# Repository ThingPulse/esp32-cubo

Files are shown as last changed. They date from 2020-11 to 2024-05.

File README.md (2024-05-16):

# ESP32-Cubo

The ESP32-Cubo is a device based on the Espressif ESP32 and comes with the following hardware:
- ESP32 Wrover-B Microcontroller module with 4MB Flash and 8MB SPIRAM memory
- Good Display 1.54" epaper display with 200x200 Black and White Pixels
- Battery charger and connector for LiPo battery
- USB connector for programming and charging
- CP2104 USB-to-Serial Chip
- 2x User controllable LEDs, red and green
- Inertial Measurement Unit ADXL345
- MAX17055 Fuel Gauge Chip for measuring battery voltage and estimating remaining capacity
- DS3231 Real Time Clock Chip for keeping time, powered by coin cell battery
- Reset Button

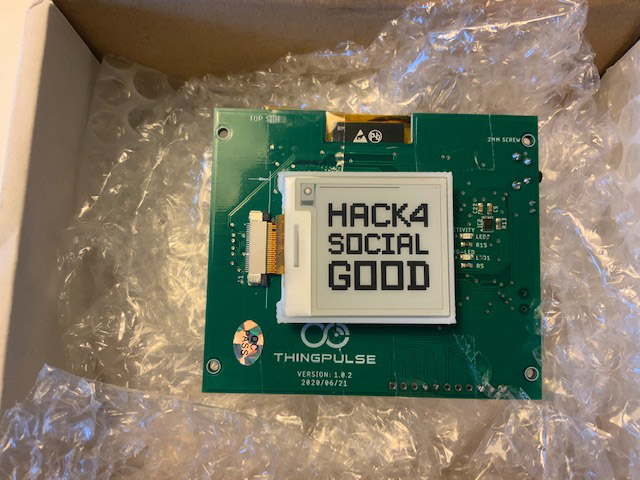
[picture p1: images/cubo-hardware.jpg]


## Template for building a cardboard mockup
[Download cardboard template](/images/Cubo_Vorlage.pdf)

## Prerequisites
- esp32-cubo hardware
- usb cable to connect your computer to the device. 
- git installed on your command line
- experience in programming the ESP32 by using the Arduino platform

## Install the CP2102 driver

This driver is required to programm the esp32-cubo. It enables your computer to talk to the USB-to-Serial chip on the PCB.
To install the driver please follow the instructions under https://www.silabs.com/developers/usb-to-uart-bridge-vcp-drivers

## Setup Development environment

This sample code should in theory work with the Arduino IDE. Instead we suggest to use the Platformio IDE since it makes it
much easier to handle the correct libraries.

Platform IO IDE is a plugin for Microsoft's Visual Studio Code Editor. To install the Platformio IDE please follow
these instructions: https://platformio.org/install/ide?install=vscode

## Get the Code

To get the sample code run 

```
git clone https://github.com/thingpulse/esp32-cubo
```
from your command line or download the zip file from https://github.com/ThingPulse/esp32-cubo/archive/master.zip and unpack it. 

## Components Explained

### The ePaper Display

The 1.54" ePaper display has 200x200 black and white pixels. The display can maintain the state of the pixels even without
supporting power. This makes is a great tool for devices running from batteries since it only consumes energy during updates.

In this sample we use the ThingPulse Minigrafx library to control the display. You can find more information for programming
the display here: https://github.com/ThingPulse/minigrafx/blob/master/API.md

### The ADXL345 IMU

The ADXL345 chip can measure movement/accelereation in three axes. It can wakeup the main processor from deep sleep
when movement is detected. It can also be setup to detect taps  or double taps in one of the three axes. This repository
contains a slightly modified copy of a ADXL345 driver by Korneliusz Jarzebski

## Uploading Filesystem

In order to have the files under data/ available they need to be uploaded to the device first. Platformio creates a .bin file
which is then flashed to the device. Everytime you change the content under data/ this needs to be done. To this execute the following
task: env:esp-wrover-kit > Platform > Upload Filesystem Image

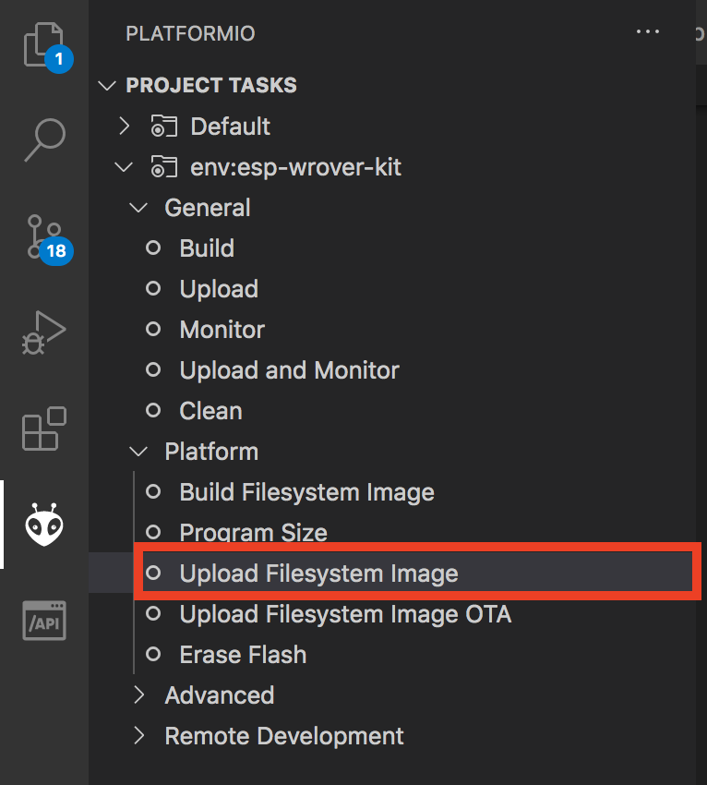
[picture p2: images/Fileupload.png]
File Upload


## Upload Code

To compile the code you can click on the checkmark icon in VS Code's footer. The arrow to the right will do the same and upload
the binary to the device. To plug icon turns on the serial console to monitor what is happening on the device.

Visual Studio Code Footer

## License

Copyright (c) 2020 - 2024, ThingPulse Ltd., Switzerland. All rights reserved.
Hardware is licensed under Creative Commons [CC BY-SA 4.0](https://creativecommons.org/licenses/by-sa/4.0/).
Software is licensed under MIT License, see [LICENSE](LICENSE).

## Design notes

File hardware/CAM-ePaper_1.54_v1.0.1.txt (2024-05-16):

{
    "author": {
        "email": "support.eagle@autodesk.com",
        "name": "Autodesk EAGLE"
    },
    "description": {
        "EN": "EAGLE default 2 layer CAM job."
    },
    "output_type": "zip",
    "outputs": [
        {
            "filename_prefix": "CAMOutputs/GerberFiles",
            "format_specifier": {
                "decimal": 4,
                "integer": 3
            },
            "generate_job_file": true,
            "output_type": "gerber",
            "outputs": [
                {
                    "advanced_options": {
                        "mirror": false,
                        "offset_x": 0,
                        "offset_y": 0,
                        "rotate": false,
                        "upside_down": false
                    },
                    "board_outline": false,
                    "config": {
                        "file_function": "Copper",
                        "layer": 1,
                        "layer_details": "mixed",
                        "layer_type": "top"
                    },
                    "filename_format": "%PREFIX/copper_top.gbr",
                    "layers": [
                        1,
                        17,
                        18
                    ],
                    "name": "Top Copper",
                    "polarity": "positive",
                    "type": "gerber_layer"
                },
                {
                    "advanced_options": {
                        "mirror": false,
                        "offset_x": 0,
                        "offset_y": 0,
                        "rotate": false,
                        "upside_down": false
                    },
                    "board_outline": false,
                    "config": {
                        "file_function": "Copper",
                        "layer": 2,
                        "layer_details": "mixed",
                        "layer_type": "bottom"
                    },
                    "filename_format": "%PREFIX/copper_bottom.gbr",
                    "layers": [
                        16,
                        17,
                        18
                    ],
                    "name": "Bottom Copper",
                    "polarity": "positive",
                    "type": "gerber_layer"
                },
                {
                    "advanced_options": {
                        "mirror": false,
                        "offset_x": 0,
                        "offset_y": 0,
                        "rotate": false,
                        "upside_down": false
                    },
                    "board_outline": true,
                    "config": {
                        "file_function": "Profile",
                        "plating": "non-plated"
                    },
                    "filename_format": "%PREFIX/profile.gbr",
                    "layers": [
                    ],
                    "milling": true,
                    "polarity": "positive",
                    "type": "gerber_layer"
                },
                {
                    "advanced_options": {
                        "mirror": false,
                        "offset_x": 0,
                        "offset_y": 0,
                        "rotate": false,
                        "upside_down": false
                    },
                    "board_outline": false,
                    "config": {
                        "file_function": "Soldermask",
                        "index": 1,
                        "layer_type": "top"
                    },
                    "filename_format": "%PREFIX/soldermask_top.gbr",
                    "layers": [
                        29
                    ],
                    "name": "Soldermask Top",
                    "polarity": "positive",
                    "type": "gerber_layer"
                },
                {
                    "advanced_options": {
                        "mirror": false,
                        "offset_x": 0,
                        "offset_y": 0,
                        "rotate": false,
                        "upside_down": false
                    },
                    "board_outline": false,
                    "config": {
                        "file_function": "Soldermask",
                        "index": 1,
                        "layer_type": "bottom"
                    },
                    "filename_format": "%PREFIX/soldermask_bottom.gbr",
                    "layers": [
                        30
                    ],
                    "name": "Soldermask Bottom",
                    "polarity": "positive",
                    "type": "gerber_layer"
                },
                {
                    "advanced_options": {
                        "mirror": false,
                        "offset_x": 0,
                        "offset_y": 0,
                        "rotate": false,
                        "upside_down": false
                    },
                    "board_outline": false,
                    "config": {
                        "file_function": "Paste",
                        "layer_type": "top"
                    },
                    "filename_format": "%PREFIX/solderpaste_top.gbr",
                    "layers": [
                        31
                    ],
                    "milling": false,
                    "name": "Solderpaste Top",
                    "polarity": "positive",
                    "type": "gerber_layer"
                },
                {
                    "advanced_options": {
                        "mirror": false,
                        "offset_x": 0,
                        "offset_y": 0,
                        "rotate": false,
                        "upside_down": false
                    },
                    "board_outline": false,
                    "config": {
                        "file_function": "Paste",
                        "layer_type": "bottom"
                    },
                    "filename_format": "%PREFIX/solderpaste_bottom.gbr",
                    "layers": [
                        32
                    ],
                    "milling": false,
                    "name": "Solderpaste Bottom",
                    "polarity": "positive",
                    "type": "gerber_layer"
                },
                {
                    "advanced_options": {
                        "mirror": false,
                        "offset_x": 0,
                        "offset_y": 0,
                        "rotate": false,
                        "upside_down": false
                    },
                    "board_outline": false,
                    "config": {
                        "file_function": "Legend",
                        "index": 1,
                        "layer_type": "top"
                    },
                    "filename_format": "%PREFIX/silkscreen_top.gbr",
                    "layers": [
                        21,
                        25,
                        51
                    ],
                    "milling": false,
                    "name": "Silkscreen Top",
                    "polarity": "positive",
                    "type": "gerber_layer"
                },
                {
                    "advanced_options": {
                        "mirror": false,
                        "offset_x": 0,
                        "offset_y": 0,
                        "rotate": false,
                        "upside_down": false
                    },
                    "board_outline": false,
                    "config": {
                        "file_function": "Legend",
                        "index": 1,
                        "layer_type": "bottom"
                    },
                    "filename_format": "%PREFIX/silkscreen_bottom.gbr",
                    "layers": [
                        22,
                        26,
                        52
                    ],
                    "milling": false,
                    "name": "Silkscreen Bottom",
                    "polarity": "positive",
                    "type": "gerber_layer"
                }
            ],
            "version": "RS274X"
        },
        {
            "filename_prefix": "CAMOutputs/DrillFiles",
            "format_specifier": {
                "decimal": 3,
                "integer": 3
            },
            "output_type": "drill",
            "outputs": [
                {
                    "advanced_options": {
                        "mirror": false,
                        "offset_x": 0,
                        "offset_y": 0,
                        "rotate": false,
                        "upside_down": false
                    },
                    "filename_format": "%DRILLPREFIX/drill_%FROM_%TO.xln",
                    "name": "Auto Drill",
                    "type": "autodrills"
                }
            ]
        },
        {
            "filename_prefix": "CAMOutputs/Assembly",
            "output_type": "assembly",
            "outputs": [
                {
                    "filename_format": "%ASSEMBLYPREFIX/%N",
                    "list_attribute": true,
                    "list_type": "values",
                    "name": "Bill of Material",
                    "output_format": "txt",
                    "type": "bom"
                },
                {
                    "filename_format": "%ASSEMBLYPREFIX/PnP_%N_%BOARDSIDE",
                    "name": "Pick and Place",
                    "output_format": "txt",
                    "type": "pick_and_place"
                }
            ]
        },
        {
            "filename_prefix": "CAMOutputs/DrawingFiles",
            "output_type": "drawing",
            "outputs": [
            ]
        }
    ],
    "timestamp": "2019-07-17T17:48:33",
    "type": "EAGLE CAM job",
    "units": "metric",
    "version": "9.2.0"
}

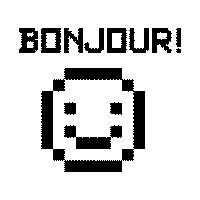
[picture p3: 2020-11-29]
images/1bit/Bonjour_01.bmp

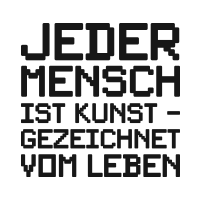
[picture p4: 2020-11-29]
images/orig/Spruch_01.bmp

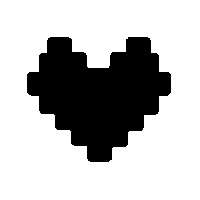
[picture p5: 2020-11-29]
images/orig/Heart.bmp

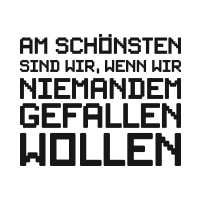
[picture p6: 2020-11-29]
images/orig/Spruch_02.bmp

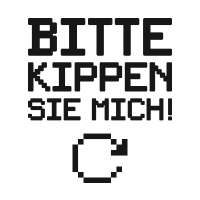
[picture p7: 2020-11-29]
images/orig/Kippen.bmp

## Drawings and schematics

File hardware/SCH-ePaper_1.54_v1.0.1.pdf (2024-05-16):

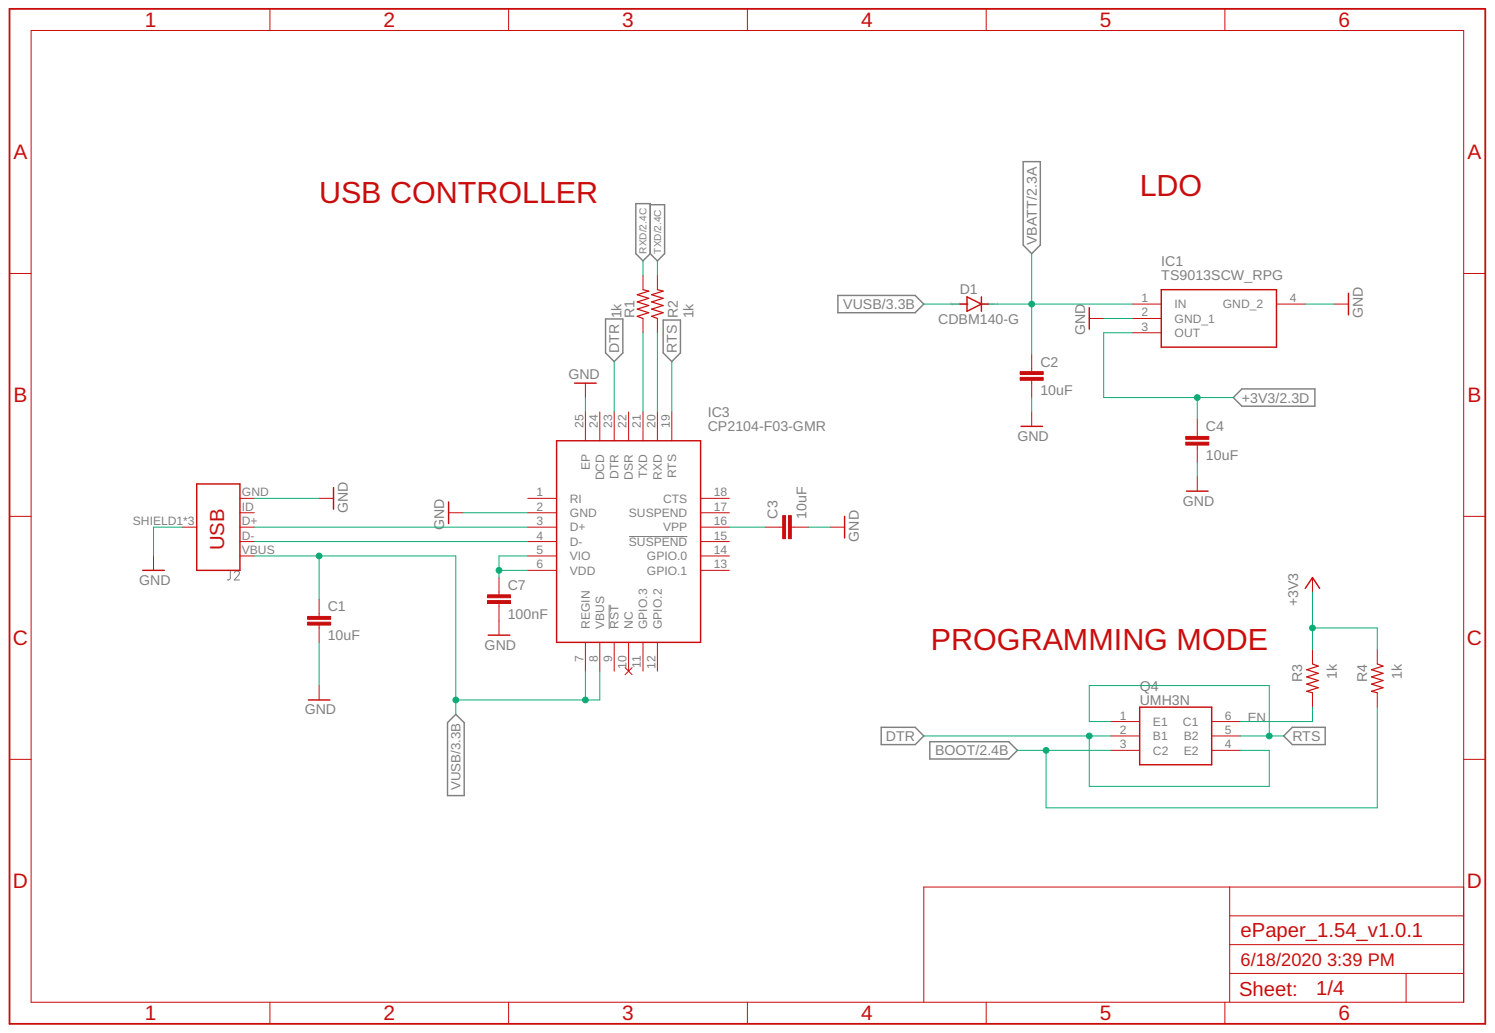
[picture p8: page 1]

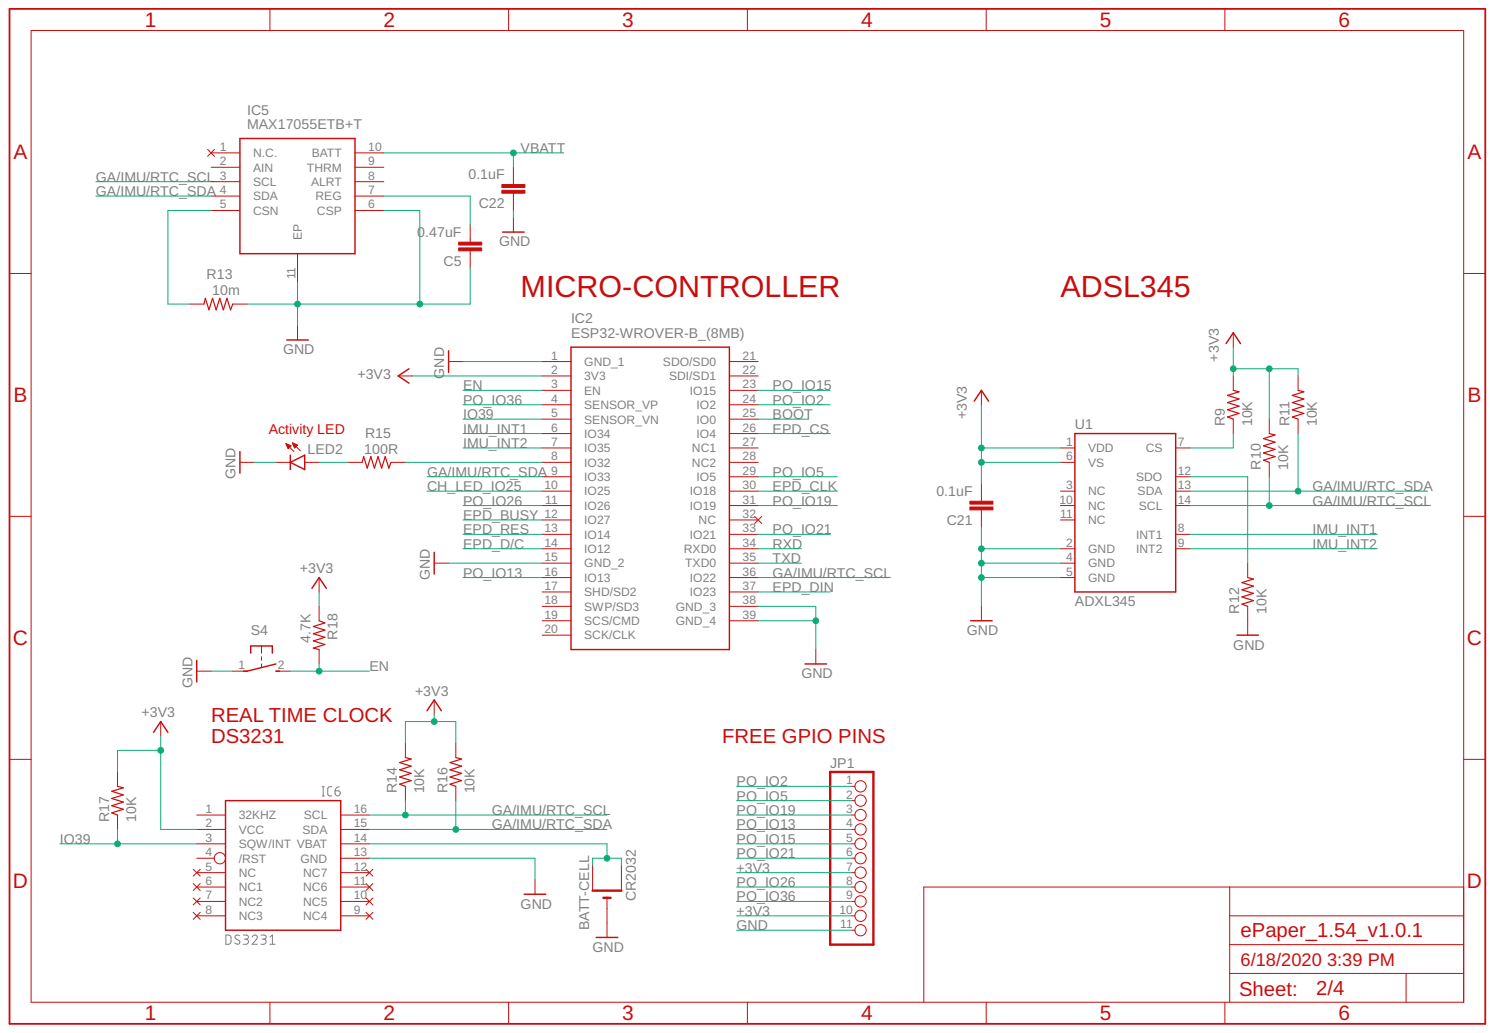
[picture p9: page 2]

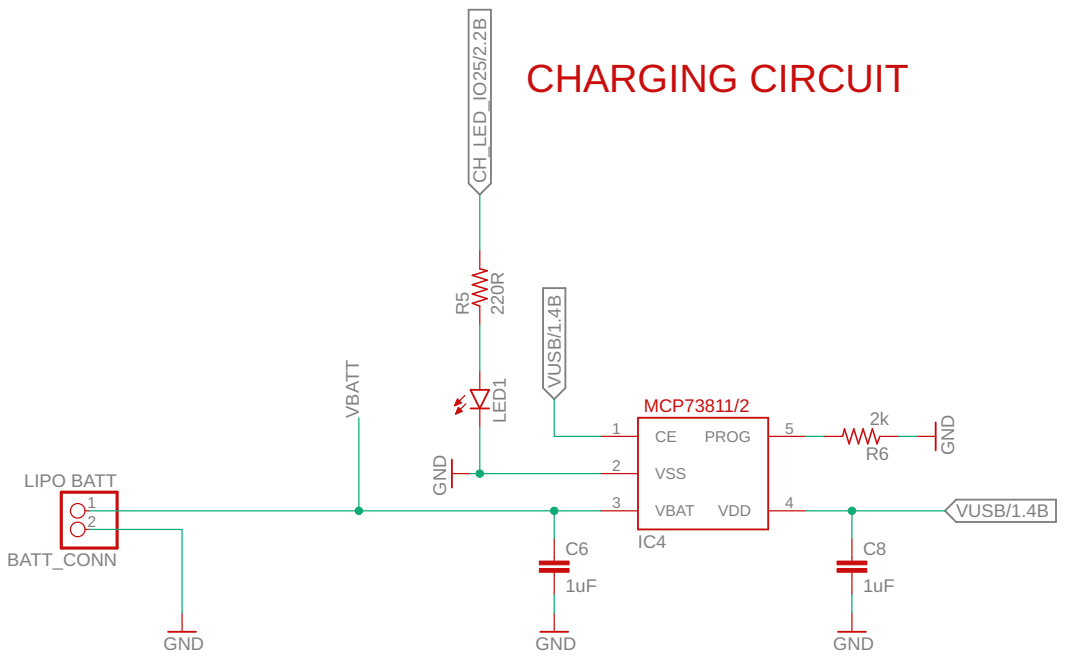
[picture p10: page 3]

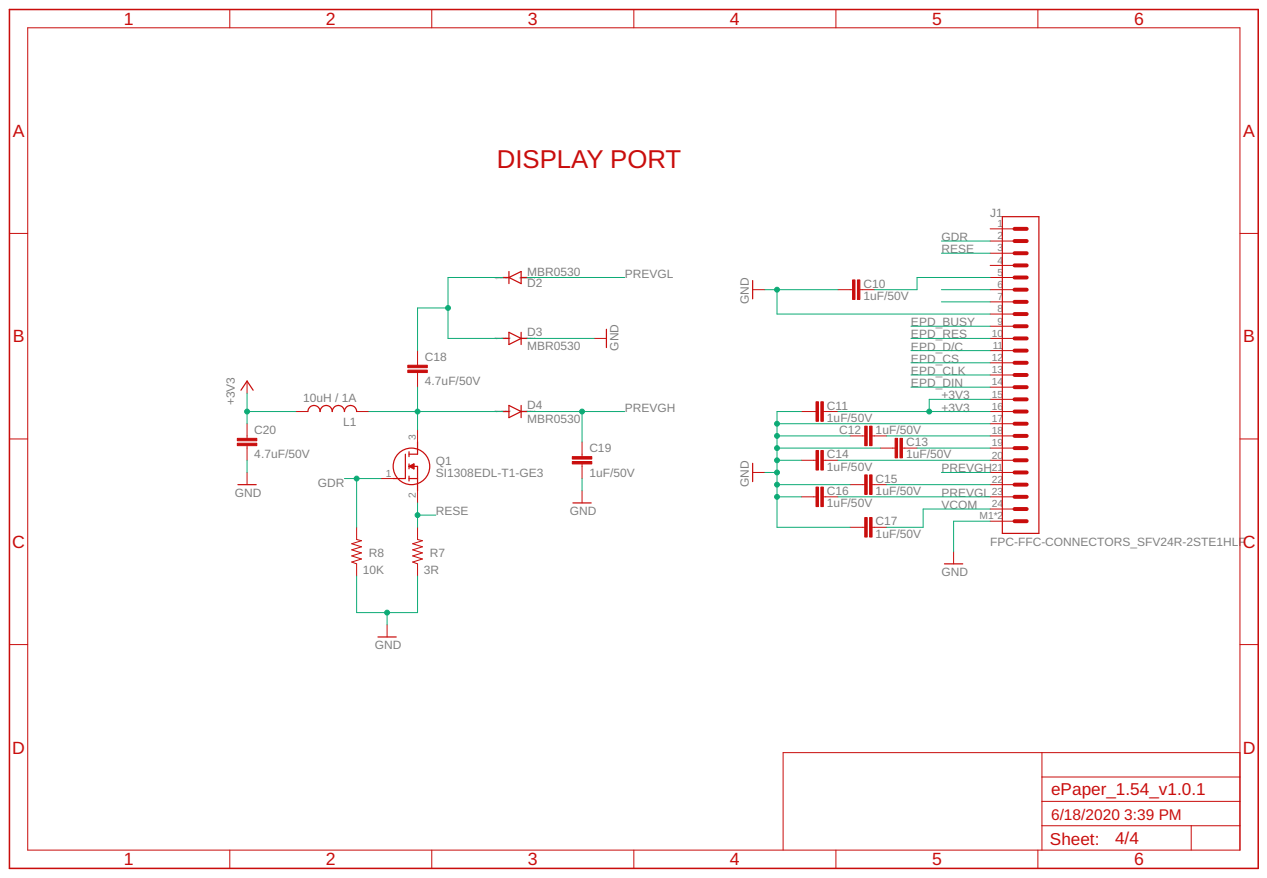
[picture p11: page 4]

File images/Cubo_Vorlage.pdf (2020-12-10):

## Anleitung

# Cubo

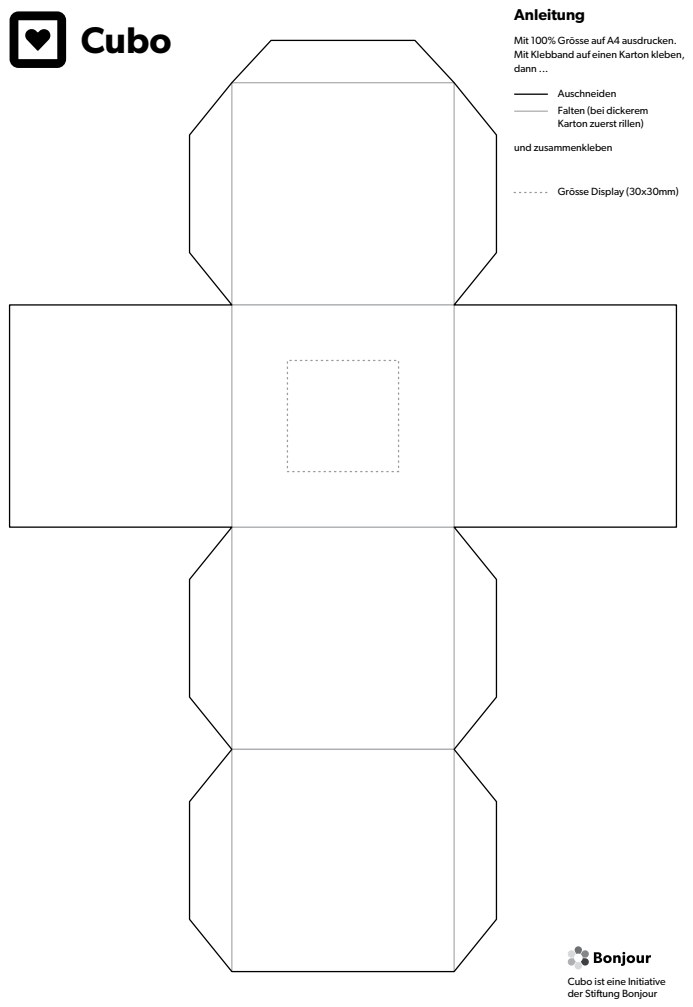
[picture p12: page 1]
und zusammenkleben; Grösse Display (30x30mm)

Mit 100% Grösse auf A4 ausdrucken.
Mit Klebband auf einen Karton kleben,
dann ...

Auschneiden
Falten (bei dickerem
Karton zuerst rillen)

Cubo ist eine Initiative
der Stiung Bonjour

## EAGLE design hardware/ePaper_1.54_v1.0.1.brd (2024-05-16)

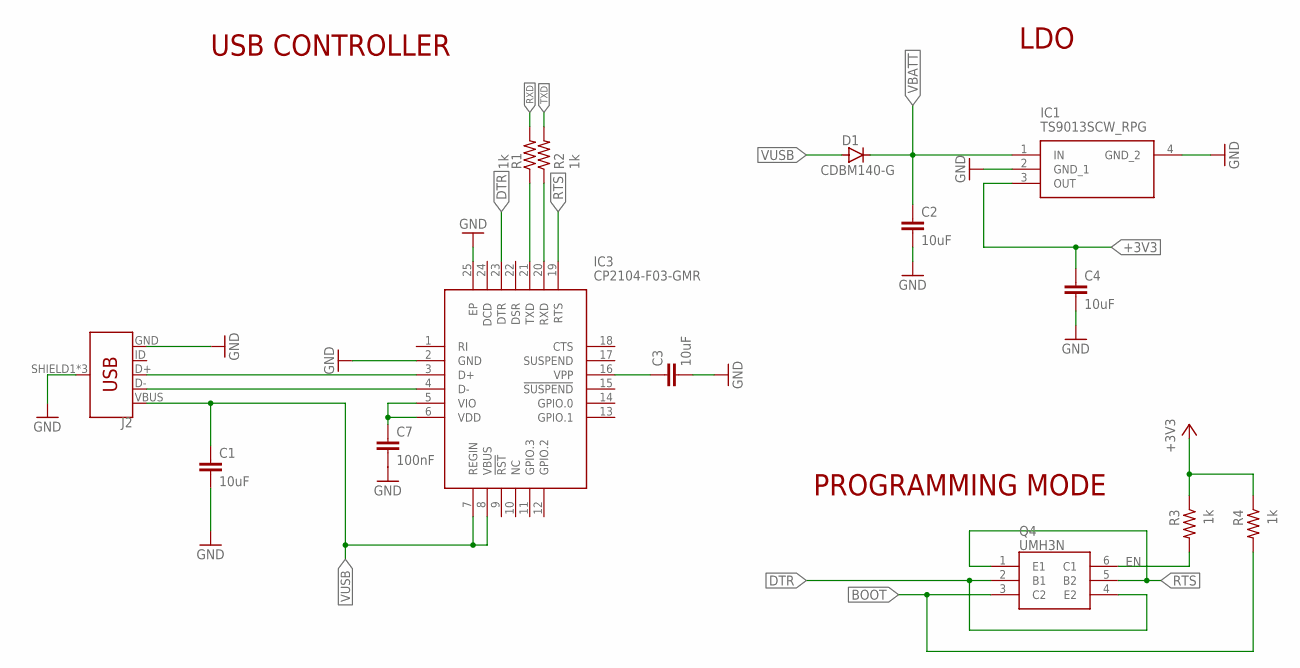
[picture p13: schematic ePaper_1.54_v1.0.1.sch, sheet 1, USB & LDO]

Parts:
C1, C2, C3, C4: 10uF; C0603
C7: 100nF; C0603
D1: CDBM140-G; SOD123
IC1: TS9013SCW_RPG; SOT230P700X180-4N
IC3: CP2104-F03-GMR; QFN50P400X400X80-25N
J2: USB_MICRO-B_FEMALE-SMT; USB-B-MICRO-SMD
Q4: UMH3N; SOT65P230X110-6N
R1, R2, R3, R4: 1k; R0603

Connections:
+3V3: C4.1, IC1.3 (OUT), R3.1, R4.1; also elsewhere on the board
BOOT: Q4.3 (C2), R4.2; also elsewhere on the board
DTR: IC3.23 (DTR), Q4.2 (B1), Q4.4 (E2)
EN: Q4.6 (C1), R3.2; also elsewhere on the board
GND: C1.2, C2.2, C3.2, C4.2, C7.2, IC1.2 (GND_1), IC1.4 (GND_2), IC3.2 (GND), IC3.25 (EP), J2.GND, J2.SHIELD1 (SHIELD), J2.SHIELD2 (SHIELD), J2.SHIELD3 (SHIELD); also elsewhere on the board
unnamed: IC3.3 (D+), J2.D+
unnamed: IC3.4 (D-), J2.D-
unnamed: C3.1, IC3.16 (VPP)
unnamed: C7.1, IC3.5 (VIO), IC3.6 (VDD)
unnamed: IC3.20 (RXD), R2.1
unnamed: IC3.21 (TXD), R1.1
RTS: IC3.19 (RTS), Q4.1 (E1), Q4.5 (B2)
RXD: R1.2; also elsewhere on the board
TXD: R2.2; also elsewhere on the board
VBATT: C2.1, D1.C, IC1.1 (IN); also elsewhere on the board
VUSB: C1.1, D1.A, IC3.7 (REGIN), IC3.8 (VBUS), J2.VBUS; also elsewhere on the board

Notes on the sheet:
USB CONTROLLER
LDO
PROGRAMMING MODE

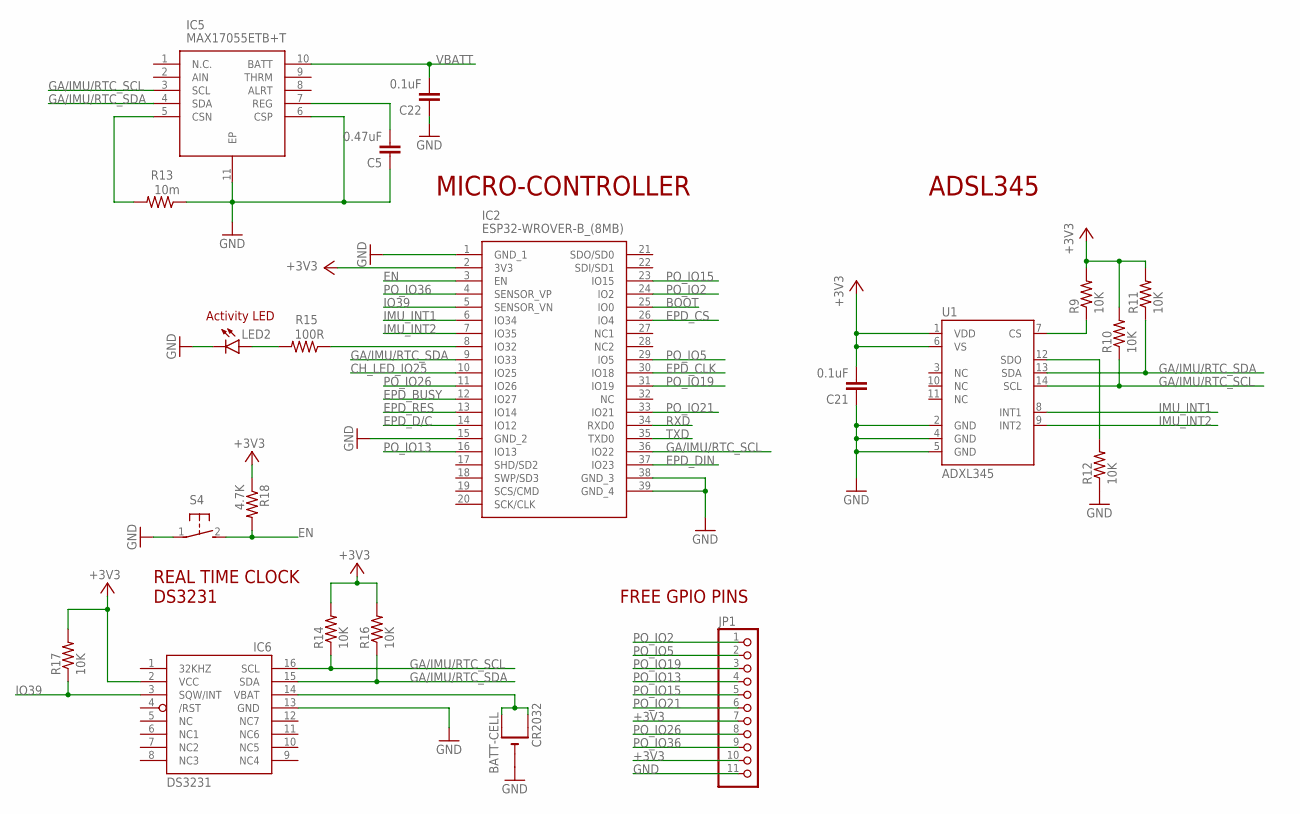
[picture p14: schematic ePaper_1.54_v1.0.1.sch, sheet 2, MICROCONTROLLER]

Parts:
BATT-CELL: CR2032; CR2032-SMD
C5: 0.47uF; C0603
C21, C22: 0.1uF; C0603
IC2: ESP32-WROVER-B_(8MB); ESP32WROVERIB8MB
IC5: MAX17055ETB+T; SON40P250X200X80-11N
IC6: DS3231/SO; SO16W
JP1: PINHD-1X11_2.54-S; 1X11-S
LED2: LEDCHIPLED_0805; CHIPLED_0805
R9, R10, R11, R12, R14, R16, R17: 10K; R0603
R13: 10m; R0603
R15: 100R; R0603
R18: 4.7K; R0603
S4: 31-XX; B3F-31XX
U1: ADXL345; LGA14

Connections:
+3V3: C21.2, IC2.2 (3V3), IC6.2 (VCC), JP1.7, JP1.10, R9.2, R10.2, R11.2, R14.2, R16.2, R17.2, R18.1, U1.1 (VDD), U1.6 (VS); also elsewhere on the board
BOOT: IC2.25 (IO0); also elsewhere on the board
CH_LED_IO25: IC2.10 (IO25); also elsewhere on the board
EN: IC2.3 (EN), R18.2, S4.2 (S); also elsewhere on the board
EPD_BUSY: IC2.12 (IO27); also elsewhere on the board
EPD_CLK: IC2.30 (IO18); also elsewhere on the board
EPD_CS: IC2.26 (IO4); also elsewhere on the board
EPD_D/C: IC2.14 (IO12); also elsewhere on the board
EPD_DIN: IC2.37 (IO23); also elsewhere on the board
EPD_RES: IC2.13 (IO14); also elsewhere on the board
GA/IMU/RTC_SCL: IC2.36 (IO22), IC5.3 (SCL), IC6.16 (SCL), R10.1, R14.1, U1.14 (SCL)
GA/IMU/RTC_SDA: IC2.9 (IO33), IC5.4 (SDA), IC6.15 (SDA), R11.1, R16.1, U1.13 (SDA)
GND: BATT-CELL.-, C5.1, C21.1, C22.1, IC2.1 (GND_1), IC2.15 (GND_2), IC2.38 (GND_3), IC2.39 (GND_4), IC5.6 (CSP), IC5.11 (EP), IC6.13 (GND), JP1.11, LED2.C, R12.1, R13.1, S4.1, U1.2 (GND), U1.4 (GND), U1.5 (GND); also elsewhere on the board
IMU_INT1: IC2.6 (IO34), U1.8 (INT1)
IMU_INT2: IC2.7 (IO35), U1.9 (INT2)
IO39: IC2.5 (SENSOR_VN), IC6.3 (SQW/INT), R17.1
unnamed: IC5.5 (CSN), R13.2
unnamed: C5.2, IC5.7 (REG)
unnamed: R12.2, U1.12 (SDO)
unnamed: R9.1, U1.7 (CS)
unnamed: BATT-CELL.+$1 (+), BATT-CELL.+$2 (+1), IC6.14 (VBAT)
unnamed: IC2.8 (IO32), R15.1
unnamed: LED2.A, R15.2
PO_IO2: IC2.24 (IO2), JP1.1
PO_IO5: IC2.29 (IO5), JP1.2
PO_IO13: IC2.16 (IO13), JP1.4
PO_IO15: IC2.23 (IO15), JP1.5
PO_IO19: IC2.31 (IO19), JP1.3
PO_IO21: IC2.33 (IO21), JP1.6
PO_IO26: IC2.11 (IO26), JP1.8
PO_IO36: IC2.4 (SENSOR_VP), JP1.9
RXD: IC2.34 (RXD0); also elsewhere on the board
TXD: IC2.35 (TXD0); also elsewhere on the board
VBATT: C22.2, IC5.10 (BATT); also elsewhere on the board

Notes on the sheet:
MICRO-CONTROLLER
ADSL345
Activity LED
FREE GPIO PINS
REAL TIME CLOCK DS3231

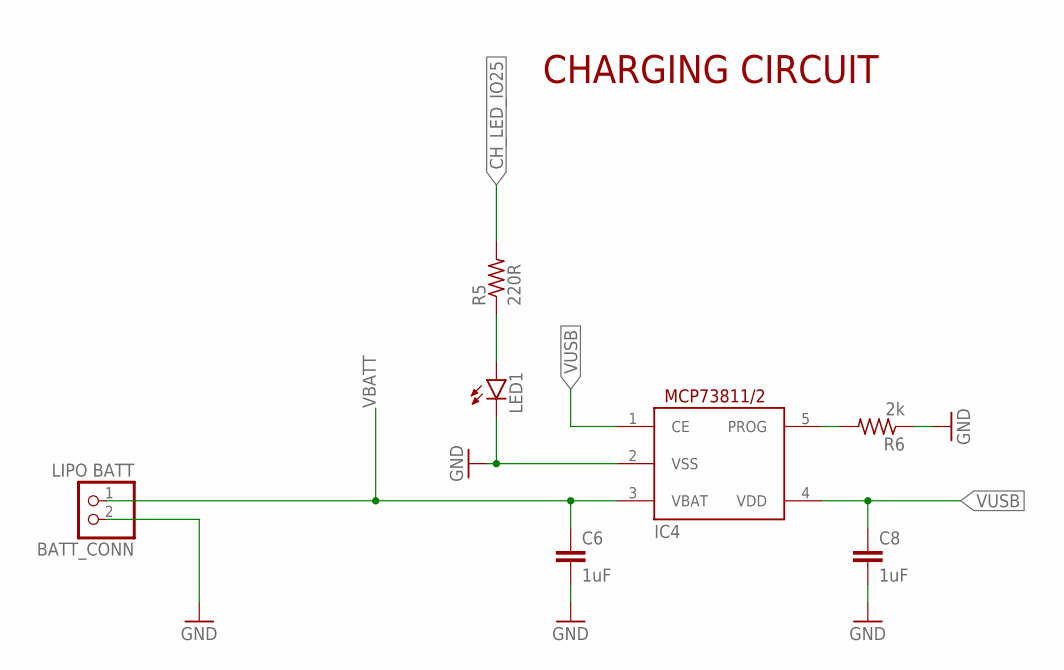
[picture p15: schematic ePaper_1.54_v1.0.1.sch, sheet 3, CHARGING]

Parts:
BATT_CONN: LIPO BATT; JST-PH-2-THM-RA
C6, C8: 1uF; C0805
IC4: MCP73811/2; SOT23-5L
LED1: LEDCHIPLED_0805; CHIPLED_0805
R5: 220R; R0603
R6: 2k; R0603

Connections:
CH_LED_IO25: R5.2; also elsewhere on the board
GND: BATT_CONN.2 (1), C6.2, C8.2, IC4.2 (VSS), LED1.C, R6.1; also elsewhere on the board
unnamed: IC4.5 (PROG), R6.2
unnamed: LED1.A, R5.1
VBATT: BATT_CONN.1 (2), C6.1, IC4.3 (VBAT); also elsewhere on the board
VUSB: C8.1, IC4.1 (CE), IC4.4 (VDD); also elsewhere on the board

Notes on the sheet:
CHARGING CIRCUIT

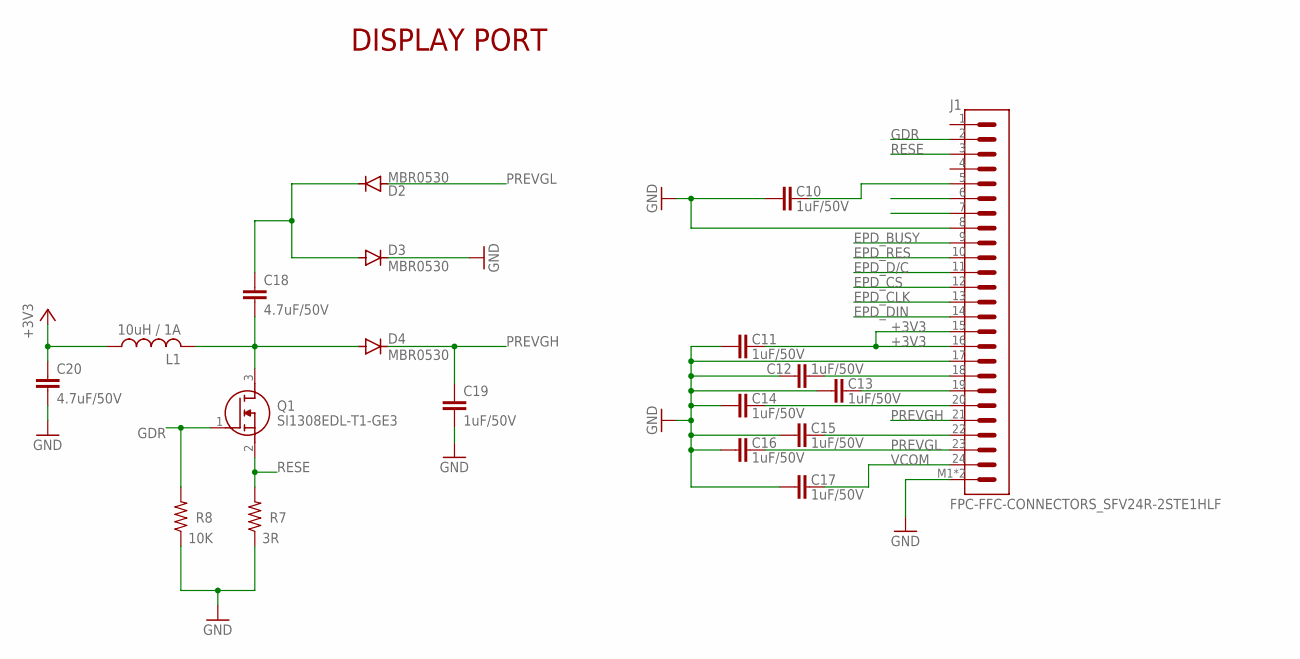
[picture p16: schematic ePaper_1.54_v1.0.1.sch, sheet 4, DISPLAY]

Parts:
C10, C11, C12, C13, C14, C15, C16, C17, C19: 1uF/50V; C0805
C18, C20: 4.7uF/50V; C0805
D2, D3, D4: MBR0530; SOD123
J1: FPC-FFC-CONNECTORS_SFV24R-2STE1HLF
L1: 10uH / 1A; L3225P
Q1: SI1308EDL-T1-GE3; SOT65P210X110-3N
R7: 3R; R0603
R8: 10K; R0603

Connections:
+3V3: C11.2, C20.2, J1.15, J1.16, L1.1; also elsewhere on the board
EPD_BUSY: J1.9; also elsewhere on the board
EPD_CLK: J1.13; also elsewhere on the board
EPD_CS: J1.12; also elsewhere on the board
EPD_D/C: J1.11; also elsewhere on the board
EPD_DIN: J1.14; also elsewhere on the board
EPD_RES: J1.10; also elsewhere on the board
GDR: J1.2, Q1.1 (G), R8.2
GND: C10.1, C11.1, C12.1, C13.1, C14.1, C15.1, C16.1, C17.1, C19.1, C20.1, D3.C, J1.8, J1.17, J1.M1 (SHIELD), J1.M2 (SHIELD), R7.1, R8.1; also elsewhere on the board
unnamed: C18.1, D4.A, L1.2, Q1.3 (D)
unnamed: C10.2, J1.5
unnamed: C18.2, D2.C, D3.A
unnamed: C12.2, J1.18
unnamed: C13.2, J1.19
unnamed: C14.2, J1.20
unnamed: C15.2, J1.22
PREVGH: C19.2, D4.C, J1.21
PREVGL: C16.2, D2.A, J1.23
RESE: J1.3, Q1.2 (S), R7.2
VCOM: C17.2, J1.24

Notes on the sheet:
DISPLAY PORT

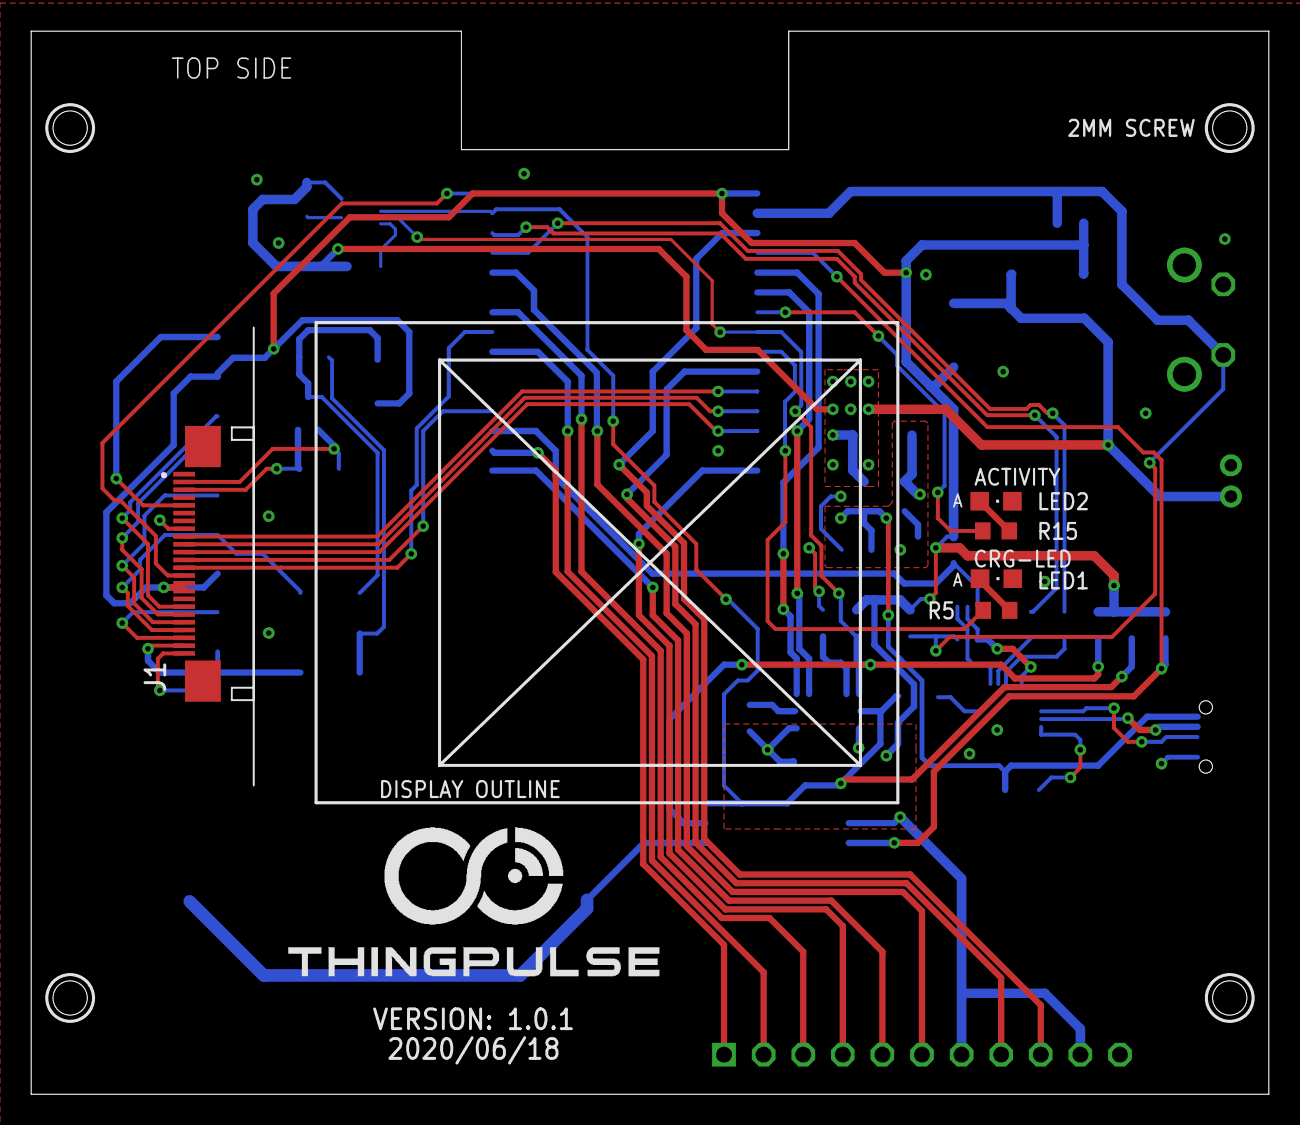
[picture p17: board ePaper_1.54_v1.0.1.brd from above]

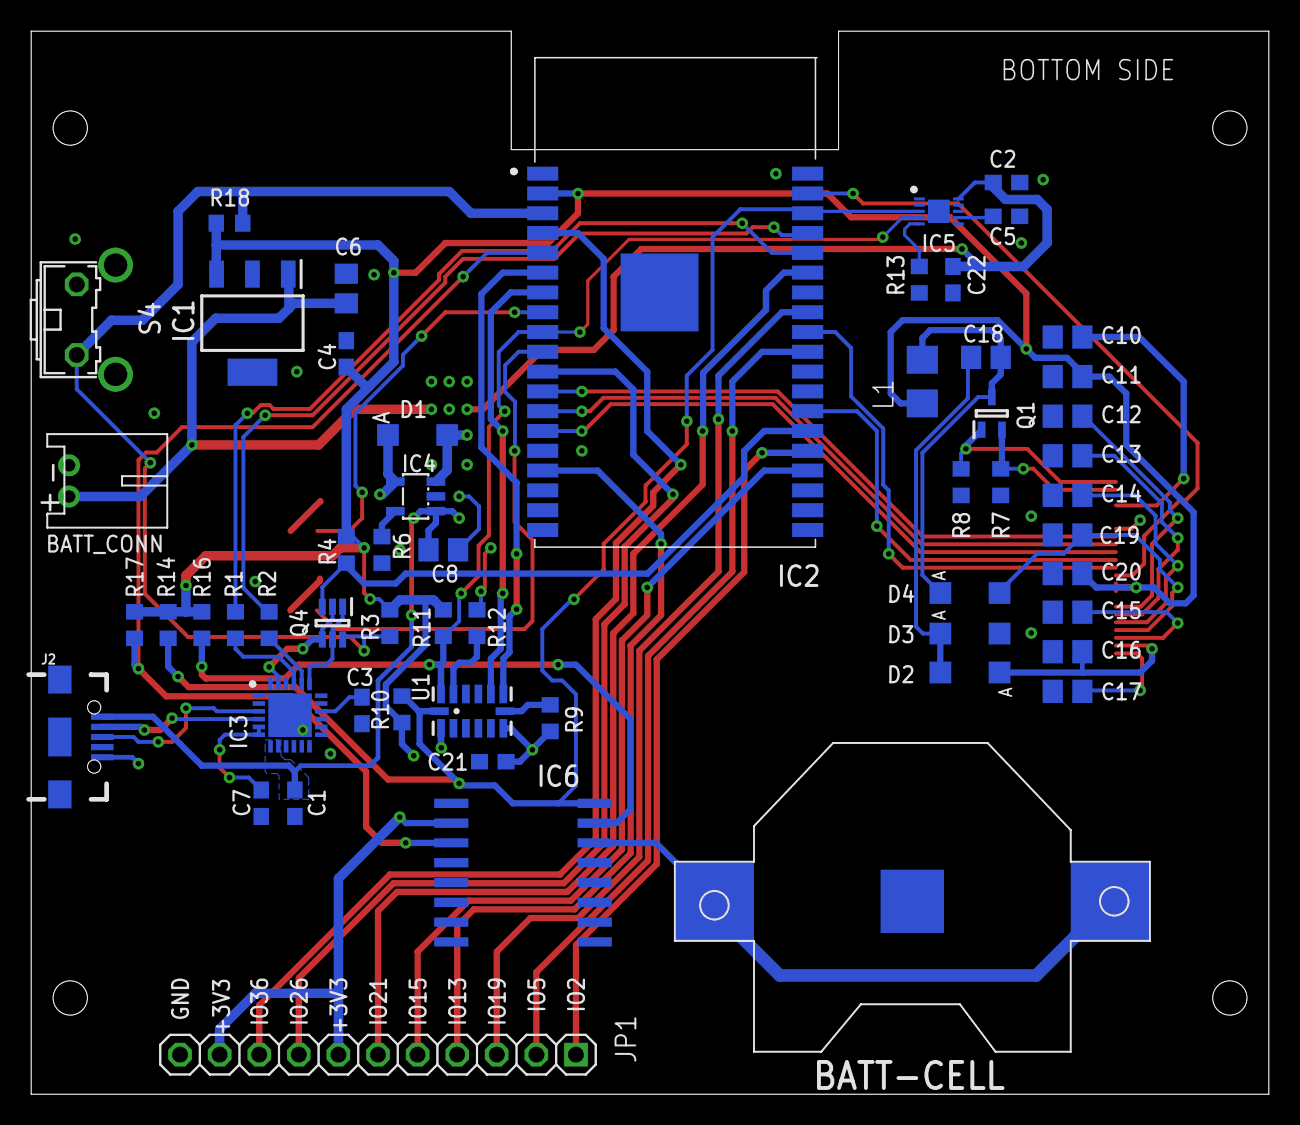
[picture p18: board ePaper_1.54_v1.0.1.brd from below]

Board: 2 copper layers, 79.4 x 68.2 mm, 61 parts (56 on the bottom side), 57 nets.

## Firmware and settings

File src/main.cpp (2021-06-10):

/*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
*/

#include <SPI.h>
#include <JPEGDecoder.h>
#include "ADXL345.h"
#include "EPD_WaveShare_154D67.h"
#include "MiniGrafx.h"
#include "DisplayDriver.h"
#include "artwork.h"
#include "settings.h"
#include "upng.h"
#include "FS.h"
#include "SPIFFS.h"

#define MINI_BLACK 0
#define MINI_WHITE 1

#define BITS_PER_PIXEL 1

#define sleepSeconds 600

extern const char willkommen[] asm("_binary_data_willkommen_hack_start");



RTC_DATA_ATTR uint8_t rotationBeforeSleep = -1;


uint16_t palette[] = {0, 1};
boolean isFastRefreshEnabled = false;

EPD_WaveShare154D67 epd(EPD_CS, EPD_RST, EPD_DC, EPD_BUSY);
MiniGrafx screenGfx = MiniGrafx(&epd, BITS_PER_PIXEL, palette, EPD_WIDTH, EPD_HEIGHT);

upng_t* upng;
uint16_t width, height, depth, iconWidth;
#define FORMAT_SPIFFS_IF_FAILED true

uint8_t counter = 0;
uint8_t rotation = 0;
uint8_t mode = 0;
boolean modeChanged = true;

#define REPETITIONS 10
#define MODES 4

ADXL345 accelerometer;

void wakeup() {

}

uint8_t getRotation() {
    uint8_t sampleCount = 10;
    Vector norm = accelerometer.readNormalize();
    Serial.printf("x: %d, y: %d, z: %d\n", norm.XAxis, norm.YAxis, norm.ZAxis);
    // We need to read activities to flush FIFO buffer
    Activites activites = accelerometer.readActivites();
    uint8_t rotation = 0;
    uint8_t unchangedRotationCount = 0;
    uint8_t currentRotation = 0;
    while (true) {
      if (norm.ZAxis > 8) {
        return 4;
      } else if (norm.ZAxis < -8) {
        return 5;
      } else if (norm.XAxis > 8) {
        currentRotation = 1;
      } else if (norm.XAxis < -8) {
        currentRotation = 3;
      } else if (norm.YAxis > 8) {
        currentRotation = 2;
      } else if (norm.YAxis < -8) {
        currentRotation = 0;
      } else {
        currentRotation = 6;
      }
      if (rotation == currentRotation) {
        unchangedRotationCount++;
      } else {
        rotation = currentRotation;
        unchangedRotationCount = 0;
      }

      if (unchangedRotationCount > sampleCount) {
        Serial.printf("Rotation: %d\n", rotation);
        return rotation;
      }
      delay (50);
    }
    return 0;

}

void closeFile() {

}

void drawJpeg(String filename, int xpos, int ypos) {
  char buffer[filename.length() + 1];
  filename.toCharArray(buffer, filename.length() + 1);
  
  JpegDec.decodeFile(buffer);
  uint16_t  *pImg;
  uint16_t mcu_w = JpegDec.MCUWidth;
  uint16_t mcu_h = JpegDec.MCUHeight;
  Serial.printf("MCU W/H: %d, %d\n", mcu_w, mcu_h);
  // uint32_t mcu_pixels = mcu_w * mcu_h; // total pixels
  // TODO immplmenet something to track drawtime performance
  // uint32_t drawTime = millis();

  while( JpegDec.read()){
    
    pImg = JpegDec.pImage;
    int mcu_x = (JpegDec.MCUx * mcu_w) + xpos;
    int mcu_y = (JpegDec.MCUy * mcu_h) + ypos;

      
    for (uint8_t y = 0; y < mcu_h; y++) {
      for (uint8_t x = 0; x < mcu_w; x++) {

          
          int absX = mcu_x + x;
          int absY = mcu_y + y;
          if (absX >= 0 && absX < screenGfx.getWidth() && absY >= 0 && absY < screenGfx.getHeight()) {
            // Threshold is at 50% grey to either display black or white pixel
            uint8_t colorIdx = *pImg < 32767 ? 0 : 1;
            screenGfx.setColor(colorIdx);
            //Serial.println(colorIdx);
            screenGfx.setPixel(absX, absY);

          }
          //Serial.printf("x: %d, y: %d, color: %d\n", absX, absY, pImg);
        *pImg++;
      }
    }
    
    yield();

  }

}

void drawPng(String filename, uint8_t xk, uint8_t yk) {
  upng = upng_new_from_file(filename.c_str());
  if (upng != NULL) {
    upng_decode(upng);
    upng_error errorCode = upng_get_error(upng);
    if (errorCode == UPNG_EOK) {
      width = upng_get_width(upng);
      height = upng_get_height(upng);
      depth = upng_get_bpp(upng) / 8;
      iconWidth = width / 8;
      log_d("Opened file %s", filename.c_str());
      log_d("Width: %d, height: %d, bit depth: %d", width, height, depth);
    } else {
      log_d("Failed to open file: %d", errorCode);
      return;
    }
  } else {
      log_i("Failed to load file");
      return;
  }

  log_d("Drawing %d, %d", xk, yk);
  uint16_t d, xOffset, yOffset;
  uint16_t greyLevel;


  if (upng_get_error(upng) == UPNG_EOK) {
    xOffset = xk * 8;
    yOffset = yk * 8;
    if (upng_get_format(upng) == UPNG_RGB8 || upng_get_format(upng) == UPNG_RGBA8) {
      for (uint8_t y = 0; y < height; y++) {
        for (uint8_t x = 0; x < width; x++) {
          greyLevel = 0;
          for (d = 0; d != depth; ++d) {
            greyLevel += upng_get_buffer(upng)[(y - yOffset - 1) * width * depth + (x + xOffset) * depth + (depth - d - 1)];
          }
          greyLevel = greyLevel / 3;
          screenGfx.setColor(greyLevel > 128 ? MINI_WHITE : MINI_BLACK);
          screenGfx.setPixel(x,y);
        }
      }
      log_d("Freeing resources");
    } else {
      log_d("Wrong bit depth");
    }
  }
  upng_free(upng);
}

void initIMU() {
    if (!accelerometer.begin(IMU_SDA, IMU_SCL))
    {
      Serial.println("Could not find a valid 27 sensor, check wiring!");
      delay(500);
    }

      // Set tap detection on Z-Axis
    accelerometer.setTapDetectionX(0);       // Don't check tap on X-Axis
    accelerometer.setTapDetectionY(0);       // Don't check tap on Y-Axis
    accelerometer.setTapDetectionZ(0);       // Check tap on Z-Axis
    // or
    // accelerometer.setTapDetectionXYZ(1);  // Check tap on X,Y,Z-Axis

    accelerometer.setTapThreshold(2.5);      // Recommended 2.5 g
    accelerometer.setTapDuration(0.02);      // Recommended 0.02 s
    accelerometer.setDoubleTapLatency(0.10); // Recommended 0.10 s
    accelerometer.setDoubleTapWindow(0.30);  // Recommended 0.30 s

    accelerometer.setActivityThreshold(1.1);    // Recommended 2 g
    accelerometer.setInactivityThreshold(1.5);  // Recommended 2 g
    accelerometer.setTimeInactivity(5);         // Recommended 5 s

    // Set activity detection only on X,Y,Z-Axis
    //accelerometer.setActivityXYZ(1);         // Check activity on X,Y,Z-Axis
    // or
    accelerometer.setActivityX(1);        // Check activity on X_Axis
    accelerometer.setActivityY(1);        // Check activity on Y-Axis
    accelerometer.setActivityZ(0);        // Check activity on Z-Axis

    // Set inactivity detection only on X,Y,Z-Axis
    //accelerometer.setInactivityXYZ(1);       // Check inactivity on X,Y,Z-Axis

    // Select INT 1 for get activities
    accelerometer.useInterrupt(ADXL345_INT1);
    pinMode(IMU_INT, INPUT);

    esp_sleep_enable_ext0_wakeup(IMU_INT,1);
    attachInterrupt(digitalPinToInterrupt(IMU_INT), wakeup, CHANGE);
}

void drawScreen() {
    uint8_t rotation = getRotation();
    // Only refresh screen, if rotation has changed
    if (rotation != rotationBeforeSleep) {
      screenGfx.fillBuffer(MINI_WHITE);
      screenGfx.setColor(MINI_BLACK);
      switch (rotation) {
        case 0:
          screenGfx.setRotation(3);
          drawJpeg("/Cubo_DPS_01.jpg", 0, 0);
          break;
        case 1:
          screenGfx.setRotation(0);
          drawJpeg("/Cubo_DPS_02.jpg", 0, 0);
          break;
        case 2:
          screenGfx.setRotation(1);
          drawJpeg("/Cubo_DPS_03.jpg", 0, 0);
          break;
        case 3:
          screenGfx.setRotation(2);
          drawJpeg("/Cubo_DPS_04.jpg", 0, 0);
          break;
        case 4:
          screenGfx.setRotation(1);
          drawJpeg("/Cubo_DPS_05.jpg", 0, 0);
          break;
        case 5:
          screenGfx.setRotation(1);
          drawJpeg("/Cubo_DPS_06.jpg", 0, 0);
          break;
        default:
          screenGfx.setRotation(1);
          drawJpeg("/Cubo_DPS_01.jpg", 0, 0);
          break;
      }
      screenGfx.setColor(MINI_BLACK);
      screenGfx.commit();
      rotationBeforeSleep = rotation;
    }
}


void setup() {
  Serial.begin(115200);

  Serial.printf("Rotation before last sleep: %d\n", rotationBeforeSleep);

  if(!SPIFFS.begin(FORMAT_SPIFFS_IF_FAILED)){
        Serial.println("SPIFFS Mount Failed");
        return;
  }

  screenGfx.init();
  screenGfx.setFastRefresh(false);
  screenGfx.fillBuffer(MINI_WHITE);
  screenGfx.setColor(MINI_BLACK);
  screenGfx.drawString(100, 100, String(millis()));

  initIMU();

  drawScreen();

  Serial.printf_P(PSTR("Going to sleep for: %d[s]\n"),  sleepSeconds);
  esp_sleep_enable_timer_wakeup(sleepSeconds * 1000000);
  esp_deep_sleep_start();

}

void loop() {

}

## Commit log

2020-11-26 Add IMU example code
2020-11-29 Use simplified sample
2020-12-10 Fix closing of png file. Add cubo image and template
    [main.cpp]
2021-06-10 Add images and switch to jpg, remove PSRAM dependency (slower boot up)
2024-05-16 Add hardware design files
    [ePaper_1.54_v1.0.1.brd, ePaper_1.54_v1.0.1.sch]

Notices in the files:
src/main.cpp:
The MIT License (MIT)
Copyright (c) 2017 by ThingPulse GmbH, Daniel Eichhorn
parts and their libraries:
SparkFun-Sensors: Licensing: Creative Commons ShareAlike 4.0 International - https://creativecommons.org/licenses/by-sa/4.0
